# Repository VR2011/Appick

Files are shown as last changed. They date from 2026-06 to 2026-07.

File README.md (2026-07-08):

Appick

Appick is a 4-key macropad that allows you to launch an app from a click of a button! It's loaded to launch Brave, Spotify, Steam, and Discord. It also features an OLED display that displays what app is being launched!

**You'll need to install AutoHotkey for this to work as intended. Install it [here](https://www.autohotkey.com/).** When Autohotkey is setup, download the AHK script from the repository and edit it as instructed. 

# Screenshots
Appick 3D Model:

3D Model

Schematic:

Schematic

PCB:

PCB
Render Top
Render Bottom

# Bill of Materials
- 4 Cherry MX Switches
- 4 DSA Keycaps
- 4 M3x5x4 Heatset Inserts
- 4 M3x12mm SHCS Bolts
- 1 0.91" 128x32 OLED Display
- 1 XIAO RP2040 Microcontroller
- 1 Case, 2 Printed Parts

Appick was created during Hack Club's Stardance challenge.

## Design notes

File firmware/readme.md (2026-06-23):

# appick

appick

*A short description of the keyboard/project*

* Keyboard Maintainer: [VR2011](https://github.com/VR2011)
* Hardware Supported: *The PCBs, controllers supported*
* Hardware Availability: *Links to where you can find this hardware*

Make example for this keyboard (after setting up your build environment):

    make appick:default

Flashing example for this keyboard:

    make appick:default:flash

See the [build environment setup](https://docs.qmk.fm/#/getting_started_build_tools) and the [make instructions](https://docs.qmk.fm/#/getting_started_make_guide) for more information. Brand new to QMK? Start with our [Complete Newbs Guide](https://docs.qmk.fm/#/newbs).

## Bootloader

Enter the bootloader in 3 ways:

* **Bootmagic reset**: Hold down the key at (0,0) in the matrix (usually the top left key or Escape) and plug in the keyboard
* **Physical reset button**: Briefly press the button on the back of the PCB - some may have pads you must short instead
* **Keycode in layout**: Press the key mapped to `QK_BOOT` if it is available

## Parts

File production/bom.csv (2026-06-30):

Item | Quantity | Price (Total) | Source
M3x12mm SHCS Bolt | 4 | $1.18 | https://us.store.bambulab.com/products/m3-socket-head-cap-machine-screws-shcs-1?id=42334746673288
M3x5mx4mm heatset inserts | 4 | $0 (Part of kit) | Kit
Seeedxiao RP2040 Microcontroller | 1 | $0 (Part of kit) | Kit
MX-Style Switches | 4 | $0 (Part of kit) | Kit
0.91 inch OLED display | 1 | $0 (Part of kit) | Kit
White blank DSA keycaps | 4 | $0 (Part of kit) | Kit
PCB | 1 | $0 (PCB Grant) | PCB grant
3D Printed Case | 2 | $0 (Printing Legion) | Printing Legion
4 Pin Header | 1 | $10.02 | https://www.jameco.com/z/68001-104HLF-JVP-Jameco-ValuePro-4-Pin-Straight-Male-Header-0-1-Goldtail_117560.html
 |  | TOTAL
 |  | $11.20

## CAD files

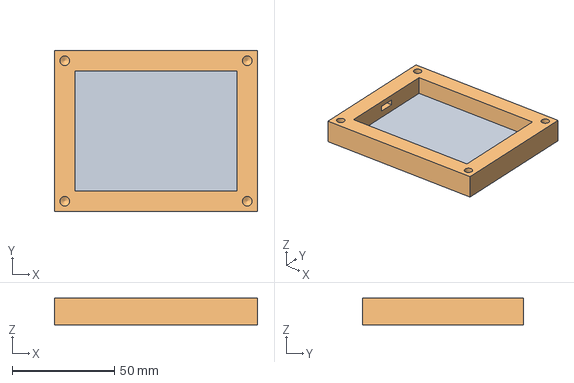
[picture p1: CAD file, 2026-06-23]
production/Bottom.step
99.3 x 78.7 x 13.0 mm

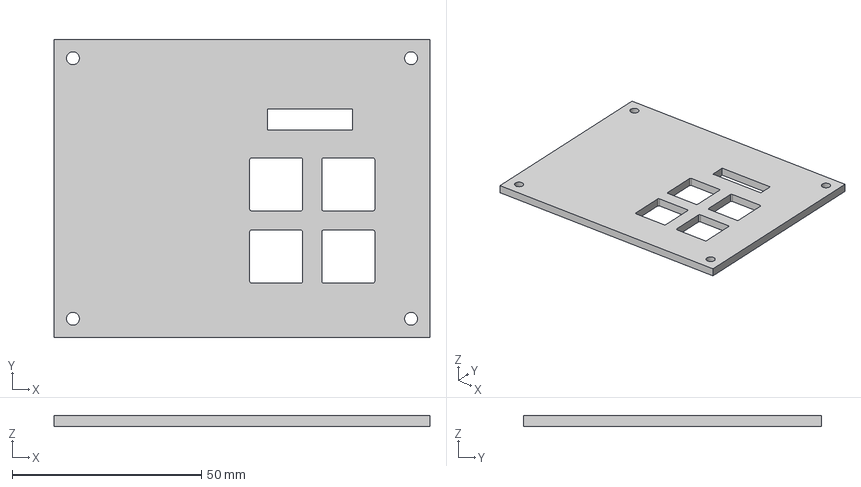
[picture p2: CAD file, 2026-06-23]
production/Top.step
99.3 x 78.8 x 3.00 mm

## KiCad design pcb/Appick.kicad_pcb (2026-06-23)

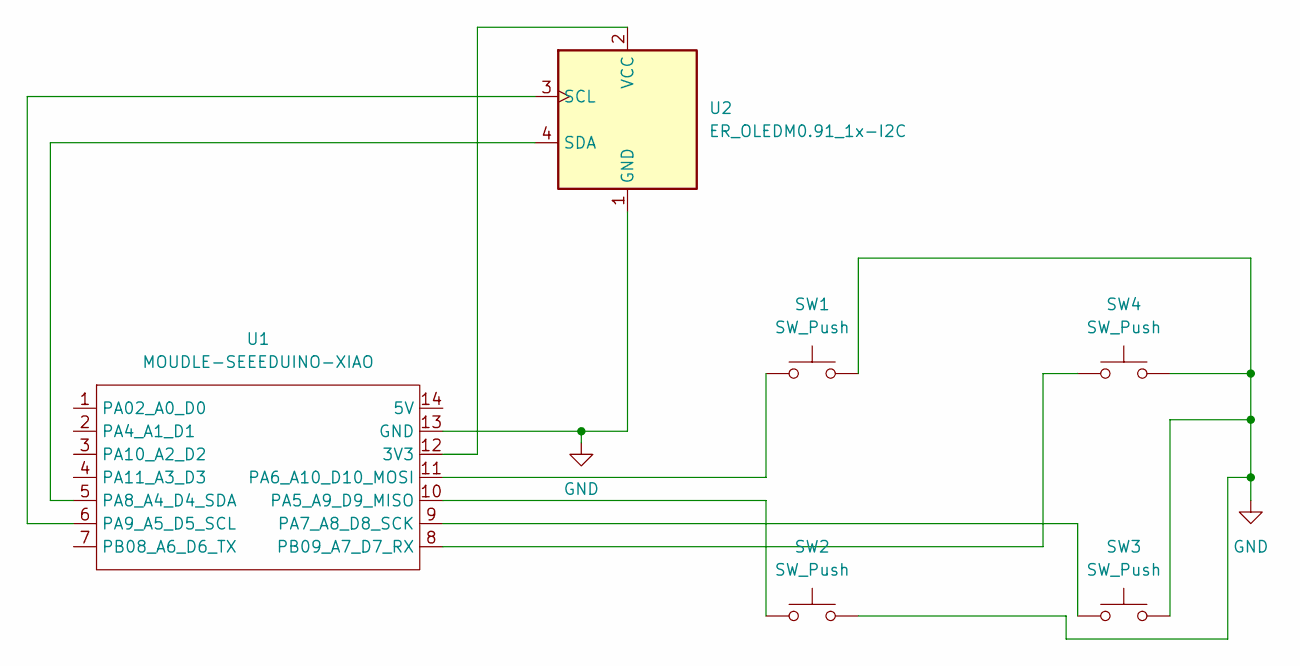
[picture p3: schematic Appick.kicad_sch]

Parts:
SW1, SW2, SW3, SW4: SW_Push; SW_Cherry_MX_1.00u_PCB
U1: MOUDLE-SEEEDUINO-XIAO; XIAO-Generic-Hybrid-14P-2.54-21X17.8MM
U2: ER_OLEDM0.91_1x-I2C

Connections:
GND: SW1.2, SW2.2, SW3.2, SW4.2, U1.13 (GND), U2.1 (GND)
unnamed: U1.12 (3V3), U2.2 (VCC)
unnamed: SW2.1, U1.10 (PA5_A9_D9_MISO)
unnamed: SW1.1, U1.11 (PA6_A10_D10_MOSI)
unnamed: SW3.1, U1.9 (PA7_A8_D8_SCK)
unnamed: U1.5 (PA8_A4_D4_SDA), U2.4 (SDA)
unnamed: U1.6 (PA9_A5_D5_SCL), U2.3 (SCL)
unnamed: SW4.1, U1.8 (PB09_A7_D7_RX)

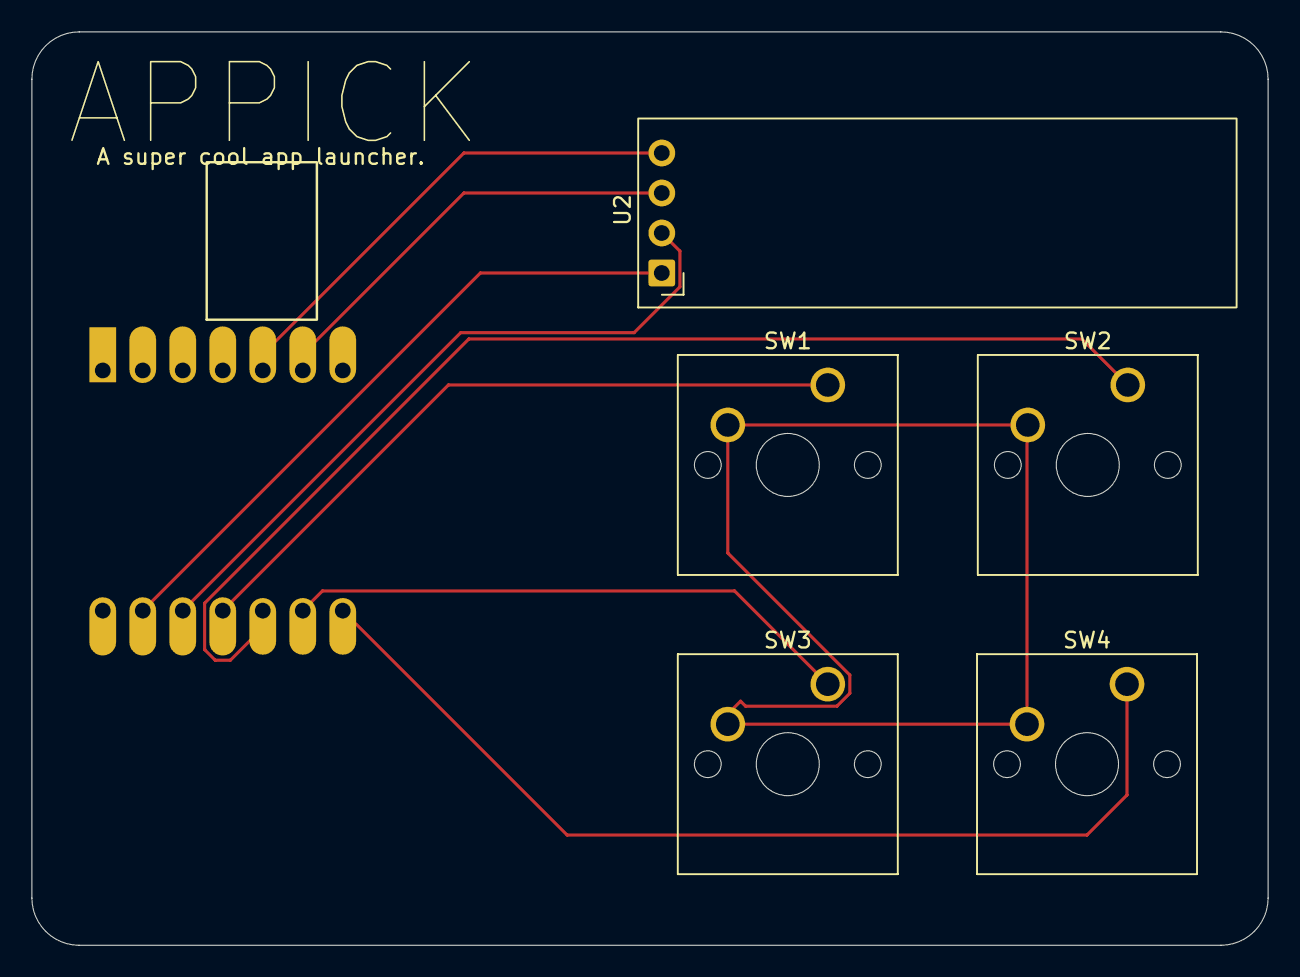
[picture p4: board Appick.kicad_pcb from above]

Board: 2 copper layers, 78.5 x 58.0 mm, 6 parts (1 on the bottom side), 8 nets.

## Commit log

2026-06-23 add pcb files
    [Appick.kicad_pcb, Appick.kicad_sch]
2026-06-23 README added
    Added detailed description, screenshots, and bill of materials for Appick.
2026-06-28 added bom.csv
    [bom.csv]
2026-06-28 fixed bom
    [bom.csv]
2026-07-08 add pcb renders
